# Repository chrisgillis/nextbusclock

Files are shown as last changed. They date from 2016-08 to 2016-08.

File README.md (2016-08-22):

# NextBus Clock
Project files for a hardware display that shows bus prediction times from NextBus

## 3D PCB
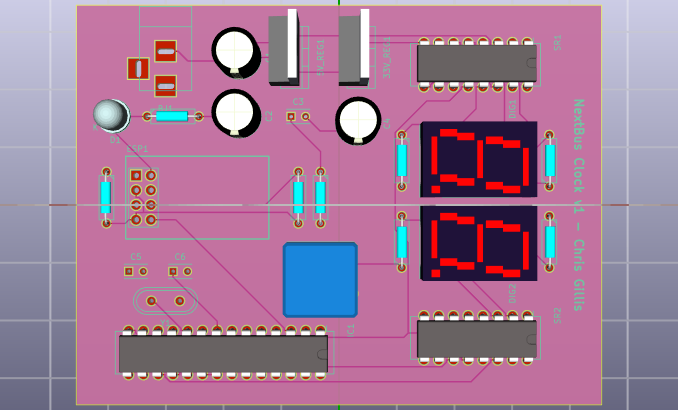
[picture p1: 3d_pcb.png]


## 2D PCB
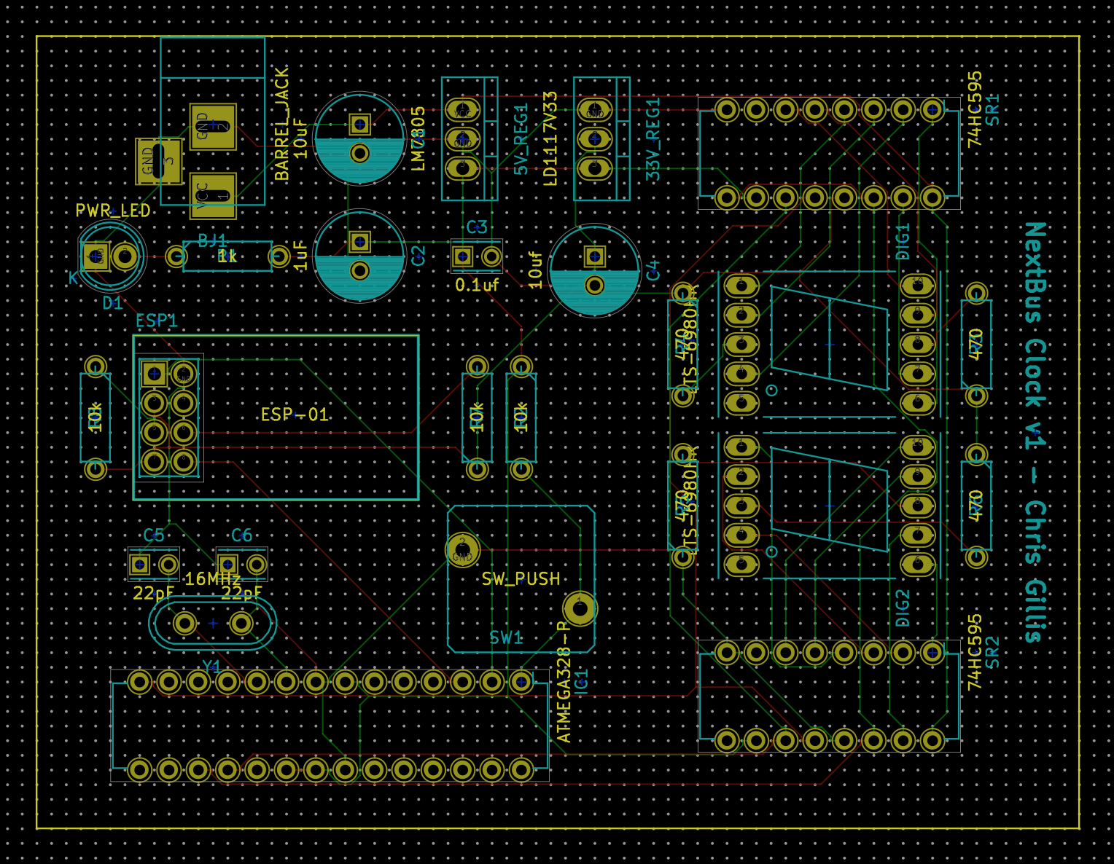
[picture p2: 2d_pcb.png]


## Schematic
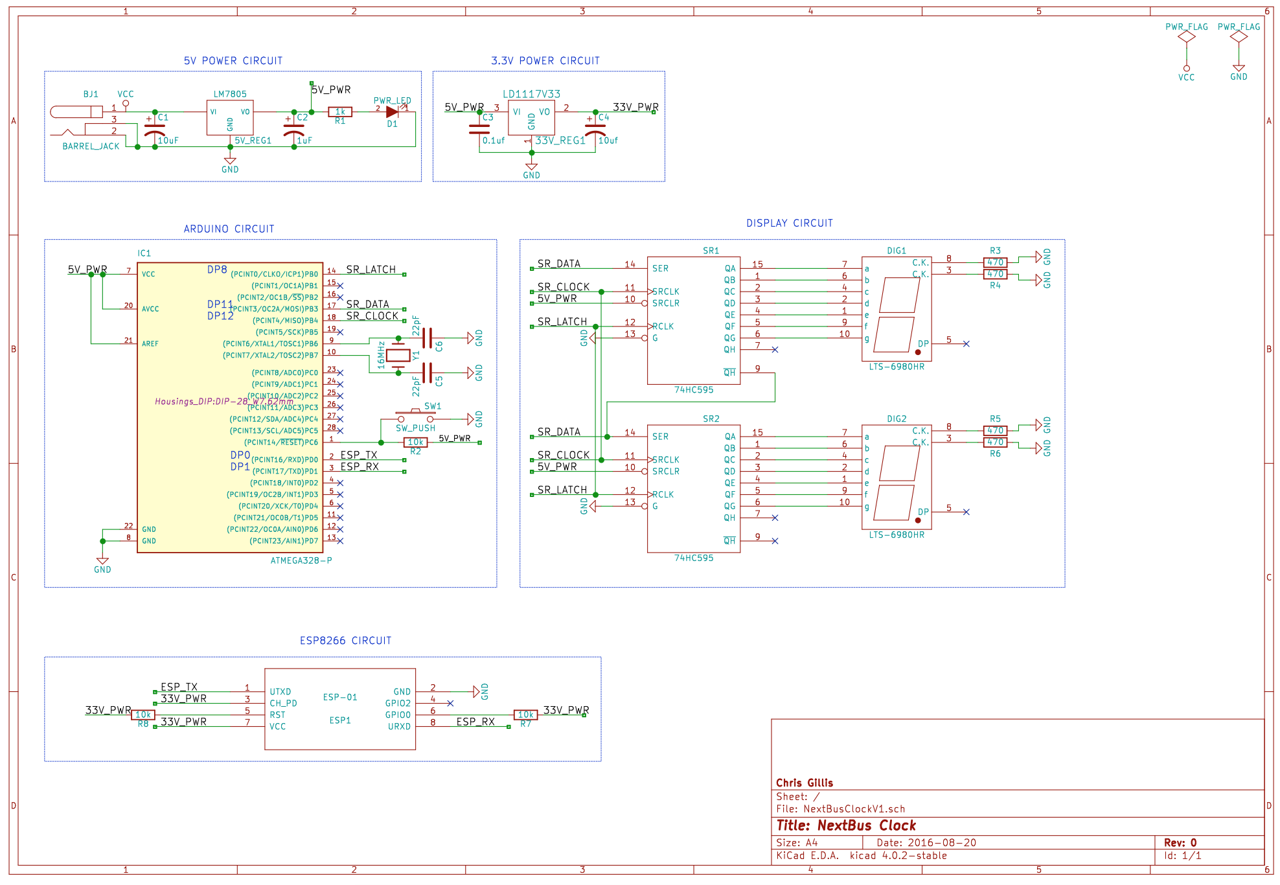
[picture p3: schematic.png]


## Component List

* 1x ATMEGA328 Microcontroller
* 1x ESP-01 Wifi Module
* 1x DIP Socket DIP-28 .3" Wide
* 2x 74HC595 Shift Register
* 2x Common Cathode 7 Segment Display
* 1x LM7805 5v Linear Regulator
* 1x LD1117V33 3.3v Linear Regulator
* 1x DC Barrel Jack
* 1x 5mm LED
* 1x 2 Pin Push Button
* 2x 10uF Capacitor
* 1x 1uF Capacitor
* 1x 0.1uF Capacitor
* 2x 22pF Capacitor
* 1x 16MHz Crystal
* 3x 10k Ohm Resistor
* 4x 470 Ohm Resistor
* 1x 1k Ohm Resistor

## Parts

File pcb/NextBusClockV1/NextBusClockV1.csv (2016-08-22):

Reference | Value | Footprint | Datasheet
BJ1 | BARREL_JACK | Connect:BARREL_JACK
C1 | 10uF | Capacitors_ThroughHole:C_Radial_D7.5_L11.2_P2.5
5V_REG1 | LM7805 | TO_SOT_Packages_THT:TO-220_Neutral123_Vertical
C2 | 1uF | Capacitors_ThroughHole:C_Radial_D7.5_L11.2_P2.5
R1 | 1k | Discret:R3-5
D1 | PWR_LED | LEDs:LED-5MM
33V_REG1 | LD1117V33 | TO_SOT_Packages_THT:TO-220_Neutral123_Vertical
C3 | 0.1uf | Capacitors_ThroughHole:C_Rect_L4_W2.5_P2.5
C4 | 10uf | Capacitors_ThroughHole:C_Radial_D7.5_L11.2_P2.5
IC1 | ATMEGA328-P | Housings_DIP:DIP-28_W7.62mm
R2 | 10k | Discret:R3-5
SW1 | SW_PUSH | Buttons_Switches_ThroughHole:SW_PUSH
Y1 | 16MHz | Crystals:Crystal_HC49-U_Vertical
C6 | 22pF | Capacitors_ThroughHole:C_Rect_L4_W2.5_P2.5
C5 | 22pF | Capacitors_ThroughHole:C_Rect_L4_W2.5_P2.5
DIG1 | LTS-6980HR | Displays_7-Segment:7SegmentLED_LTS6760_LTS6780
DIG2 | LTS-6980HR | Displays_7-Segment:7SegmentLED_LTS6760_LTS6780
R3 | 470 | Discret:R3-5
R4 | 470 | Discret:R3-5
SR1 | 74HC595 | Housings_DIP:DIP-16_W7.62mm
SR2 | 74HC595 | Housings_DIP:DIP-16_W7.62mm
R5 | 470 | Discret:R3-5
R6 | 470 | Discret:R3-5
ESP1 | ESP-01 | ESPLIB:ESP-01
R7 | 10k | Discret:R3-5
R8 | 10k | Discret:R3-5

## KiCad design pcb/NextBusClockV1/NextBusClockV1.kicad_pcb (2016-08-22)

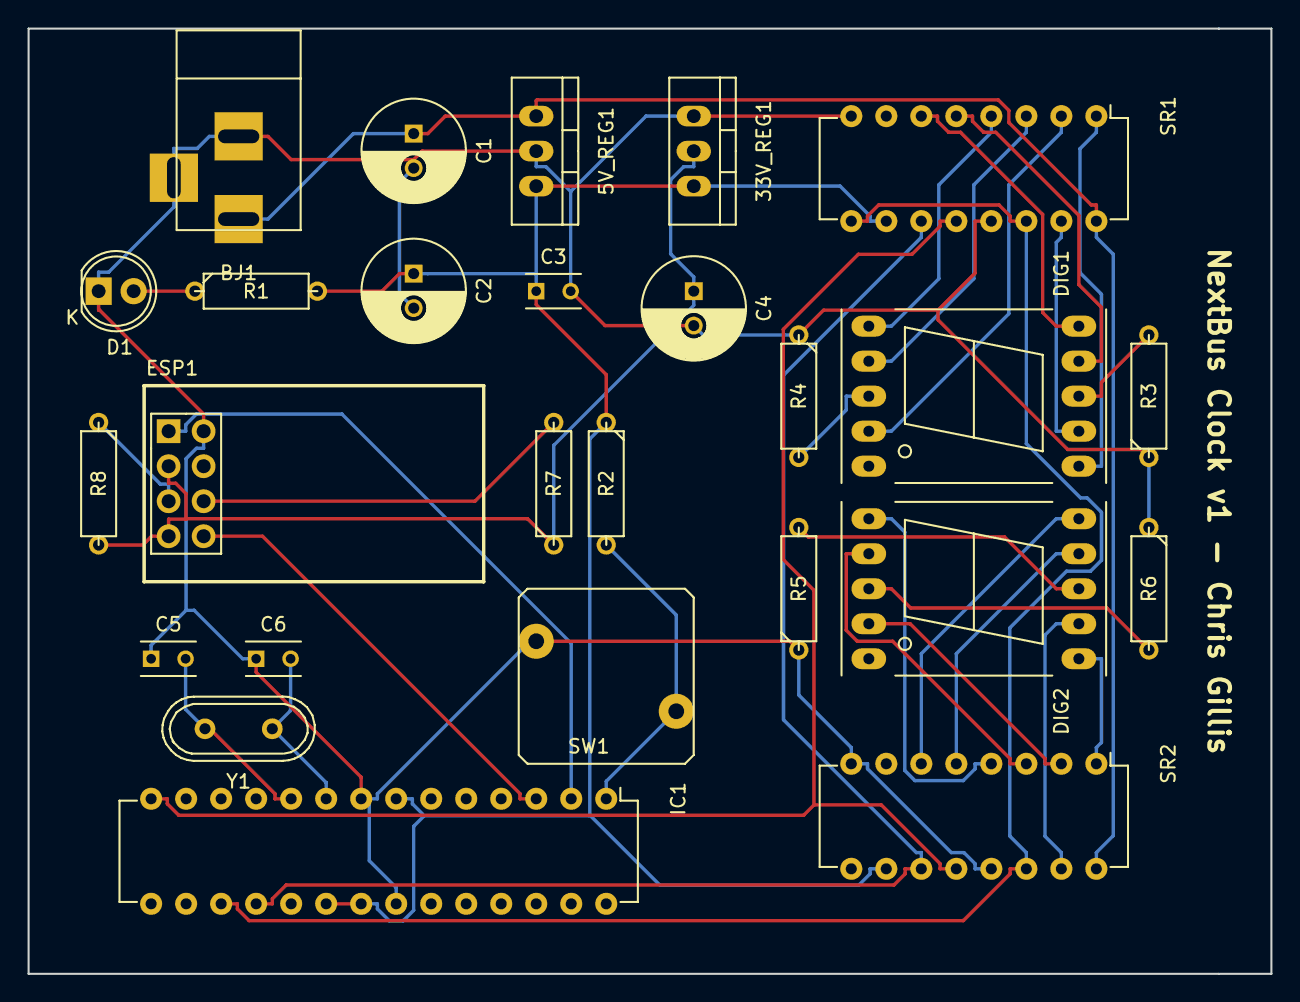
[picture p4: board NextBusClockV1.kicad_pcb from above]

Board: 2 copper layers, 90.2 x 68.6 mm, 26 parts (0 on the bottom side), 33 nets.

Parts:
5V_REG1: LM7805; TO-220_Neutral123_Vertical
33V_REG1: LD1117V33; TO-220_Neutral123_Vertical
BJ1: BARREL_JACK
C1: 10uF; C_Radial_D7.5_L11.2_P2.5
C2: 1uF; C_Radial_D7.5_L11.2_P2.5
C3: 0.1uf; C_Rect_L4_W2.5_P2.5
C4: 10uf; C_Radial_D7.5_L11.2_P2.5
C5, C6: 22pF; C_Rect_L4_W2.5_P2.5
D1: PWR_LED; LED-5MM
DIG1, DIG2: LTS-6980HR; 7SegmentLED_LTS6760_LTS6780
ESP1: ESP-01
IC1: ATMEGA328-P; DIP-28_W7.62mm
R1: 1k; R3-5
R2, R7, R8: 10k; R3-5
R3, R4, R5, R6: 470; R3-5
SR1, SR2: 74HC595; DIP-16_W7.62mm
SW1: SW_PUSH
Y1: 16MHz; Crystal_HC49-U_Vertical

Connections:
/5V_PWR: 5V_REG1.3, 33V_REG1.3, C2.1, C3.1, IC1.7, IC1.20, IC1.21, R1.2, R2.1, SR1.10, SR2.10
/33V_PWR: 33V_REG1.2, C4.1, ESP1.3, ESP1.7, R7.1, R8.2
/ESP_RX: ESP1.8, IC1.3
/ESP_TX: ESP1.1, IC1.2
/SR_CLOCK: IC1.18, SR1.11, SR2.11
/SR_DATA: IC1.17, SR1.9, SR1.14, SR2.14
/SR_LATCH: IC1.14, SR1.12, SR2.12
GND: 5V_REG1.2, 33V_REG1.1, BJ1.2, BJ1.3, C1.2, C2.2, C3.2, C4.2, C5.1, C6.1, D1.1, ESP1.2, IC1.8, IC1.22, R3.1, R4.1, R5.1, R6.1, SR1.8, SR1.13, SR2.8, SR2.13, SW1.2
unnamed: C5.2, IC1.10, Y1.2
unnamed: C6.2, IC1.9, Y1.1
unnamed: D1.2, R1.1
unnamed: DIG1.1, SR1.4
unnamed: DIG1.2, SR1.3
unnamed: DIG1.3, R4.2
unnamed: DIG1.4, SR1.2
unnamed: DIG1.6, SR1.1
unnamed: DIG1.7, SR1.15
unnamed: DIG1.8, R3.2
unnamed: DIG1.9, SR1.5
unnamed: DIG1.10, SR1.6
unnamed: DIG2.1, SR2.4
unnamed: DIG2.2, SR2.3
unnamed: DIG2.3, R6.2
unnamed: DIG2.4, SR2.2
unnamed: DIG2.6, SR2.1
unnamed: DIG2.7, SR2.15
unnamed: DIG2.8, R5.2
unnamed: DIG2.9, SR2.5
unnamed: DIG2.10, SR2.6
unnamed: ESP1.5, R8.1
unnamed: ESP1.6, R7.2
unnamed: IC1.1, R2.2, SW1.1
VCC: 5V_REG1.1, BJ1.1, C1.1, SR1.16, SR2.16

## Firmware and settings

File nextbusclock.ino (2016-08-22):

//pre mem opt: 1232b available
// post mem opt: 1430b
#include <SoftwareSerial.h>

#define SSID "HOME-9DBD"
#define PASS "BE862EA2CA5EBCE4"

SoftwareSerial dbgSerial(5, 6); // RX, TX

int minsTilNextBus = 99;

int sr1Data = 11;
int sr1Clock = 12;
int sr1Latch = 8;

byte nums[10];
byte mask[8];
byte needToCheckBus = 1;
byte digit1 = 9;
byte digit2 = 9;

unsigned long lastBusCheckMillis = 0;

  boolean connectWiFi()
  {
    Serial.println(F("AT+CWMODE=1"));
    dbgSerial.println(F("AT+CWJAP=\"HOME-9DBD\",\"BE862EA2CA5EBCE4\""));
    Serial.println(F("AT+CWJAP=\"HOME-9DBD\",\"BE862EA2CA5EBCE4\""));
    delay(2000);
    if(Serial.find("OK")) {
      dbgSerial.println(F("OK, Connected to WiFi."));
      return true;
    } else {
      dbgSerial.println(F("Can not connect to the WiFi."));
      return false;
    }
  }
   
   void setup()
   {
     pinMode(sr1Latch, OUTPUT);
     pinMode(sr1Clock, OUTPUT);
     pinMode(sr1Data, OUTPUT);

     // Clear the shift registers
     digitalWrite(sr1Latch, LOW);
     shiftOut(sr1Data, sr1Clock, MSBFIRST, 0b00000000);
     shiftOut(sr1Data, sr1Clock, MSBFIRST, 0b00000000);
     digitalWrite(sr1Latch, HIGH);
     
     nums[0] = 0b11111101;
     nums[1] = 0b01000100;
     nums[2] = 0b01111010;
     nums[3] = 0b01101110;
     nums[4] = 0b01000111;
     nums[5] = 0b00101111;
     nums[6] = 0b10111111;
     nums[7] = 0b11100100;
     nums[8] = 0b11111111;
     nums[9] = 0b11101111;

     mask[0] = 0b00000001;
     mask[1] = 0b00000010;
     mask[2] = 0b00000100;
     mask[3] = 0b00001000;
     mask[4] = 0b00010000;
     mask[5] = 0b00100000;
     mask[6] = 0b01000000;
     mask[7] = 0b10000000;

     delay(2000); // give the wifi chip a bit to boot
    
     // Open serial communications and wait for port to open:
     Serial.begin(115200);
     Serial.setTimeout(5000);
     dbgSerial.begin(115200); //can't be faster than 19200 for softserial
     dbgSerial.println(F("ESP8266 Demo"));

     //test if the module is ready
     Serial.println(F("AT+RST"));
       
     if(Serial.find("ready")) {
       dbgSerial.println(F("Module is ready"));
     } else {
       dbgSerial.println(F("Module have no response."));
       while(1);
     }
     
     delay(1000);
     
     //connect to the wifi
     boolean connected=false;
     for(int i=0;i<5;i++)
     {
       if(connectWiFi())
       {
         connected = true;
         break;
       }
     }
     
     if (!connected) {
       while(1);
     }
     
     delay(1000);
     
     //set the single connection mode
     Serial.println("AT+CIPMUX=0");
   }
   
   void loop()
   { 
     Serial.println(F("AT+CIPSTART=\"TCP\",\"162.208.48.154\",80"));
     dbgSerial.println(F("AT+CIPSTART=\"TCP\",\"162.208.48.154\",80"));
     if(Serial.find("Error")) return;
     String cmd = "GET /bus.php HTTP/1.0\r\n\r\n";
     Serial.print("AT+CIPSEND=");
     Serial.println(cmd.length());
     if(Serial.find(">")) {
       dbgSerial.print(">");
     } else {
       Serial.println(F("AT+CIPCLOSE"));
       dbgSerial.println(F("connect timeout"));
       delay(1000);
       return;
     }
       
     Serial.print(cmd);
       
     int tmr = 0;
     String rstResp = "";

     while(tmr<100) {
       if(Serial.available()) {
         char c = Serial.read();
         rstResp += c;
         tmr=0;
       } else {
         ++tmr;
         delay(10);
       }
     }
       
     int i = rstResp.indexOf("!");
     dbgSerial.print(F("MINUTESINDEX="));
     dbgSerial.println(i);
       
     int attempts = 0;
     if(i > 0) {
       String minutes = "";
       i = i + 1;
       for( ; rstResp[i] != '*'; i++) {
         if (attempts > 4) {
           break;
         }
         minutes += rstResp[i]; 
         attempts++;
       }

      dbgSerial.print(F("MINUTES_STR="));
      dbgSerial.println(minutes);

      int minutesInt = minutes.toInt();
      dbgSerial.print(F("MINUTES_INT="));
      dbgSerial.println(minutesInt);
        
      if(minutesInt != 0) {
        if(minutesInt >= 99) {
          minsTilNextBus = 99;
        } else {
          minsTilNextBus = minutesInt;
        }
      }

      dbgSerial.print(F("MINUTES_NEXT_BUS="));
      dbgSerial.println(minsTilNextBus);
      rstResp = "";

      byte nextBusMins = minsTilNextBus;
      byte digitCounter = 0;
      while (digitCounter <= 1) {
        byte digit = nextBusMins % 10;
        nextBusMins = nextBusMins / 10;

        if (digitCounter == 0) {
          digit2 = digit;
        }

        if (digitCounter == 1) {
          digit1 = digit;
        }
        
        digitCounter++;
      }
    } 

    lastBusCheckMillis = millis();
    while(millis() - lastBusCheckMillis < 10000) {
      for (byte j = 0; j <= 7; j++) {
        digitalWrite(sr1Latch, LOW);
        shiftOut(sr1Data, sr1Clock, MSBFIRST, nums[digit2] & mask[j]);
        shiftOut(sr1Data, sr1Clock, MSBFIRST, nums[digit1] & mask[j]);
        digitalWrite(sr1Latch, HIGH);
      }
    } 
  }
